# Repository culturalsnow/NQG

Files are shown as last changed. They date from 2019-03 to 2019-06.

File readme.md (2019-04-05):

# NQG: Not Quite Gherkin

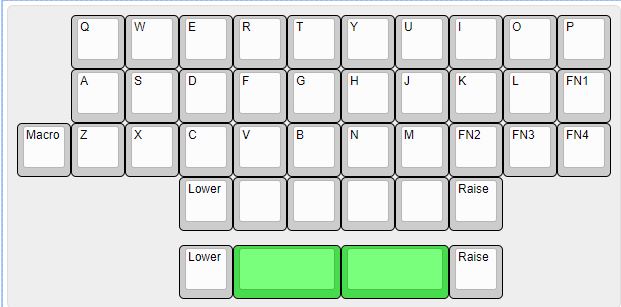
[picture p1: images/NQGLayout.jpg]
NQG


NQG (Not Quite Gherkin) is a 30% ortholinear keyboard with a macro key and dedicated row for thumb keys, made by emptystring studio.

Keyboard Maintainer: [SA_EndlessGame](http://twitter.com/SA_EndlessGame) on twitter  
Hardware Supported: NQG PCB, Pro Micro  
Hardware Availability: Kits are available from [SA_EndlessGame](http://twitter.com/SA_EndlessGame)  

Make example for this keyboard (after setting up your build environment):

    make emptystring/NQG:default

See the [build environment setup](https://docs.qmk.fm/#/getting_started_build_tools) and the [make instructions](https://docs.qmk.fm/#/getting_started_make_guide) for more information. Brand new to QMK? Start with our [Complete Newbs Guide](https://docs.qmk.fm/#/newbs).

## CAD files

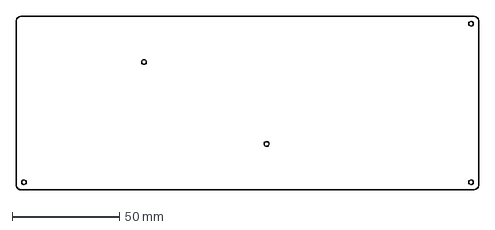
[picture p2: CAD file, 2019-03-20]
PCB/Plates/BottomPlate.dxf
215.4 x 80.8 mm

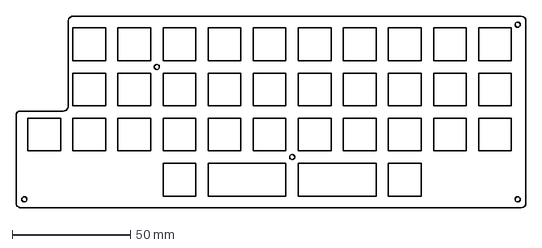
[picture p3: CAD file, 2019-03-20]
PCB/Plates/Top/TopPlate.dxf
215.4 x 80.8 mm

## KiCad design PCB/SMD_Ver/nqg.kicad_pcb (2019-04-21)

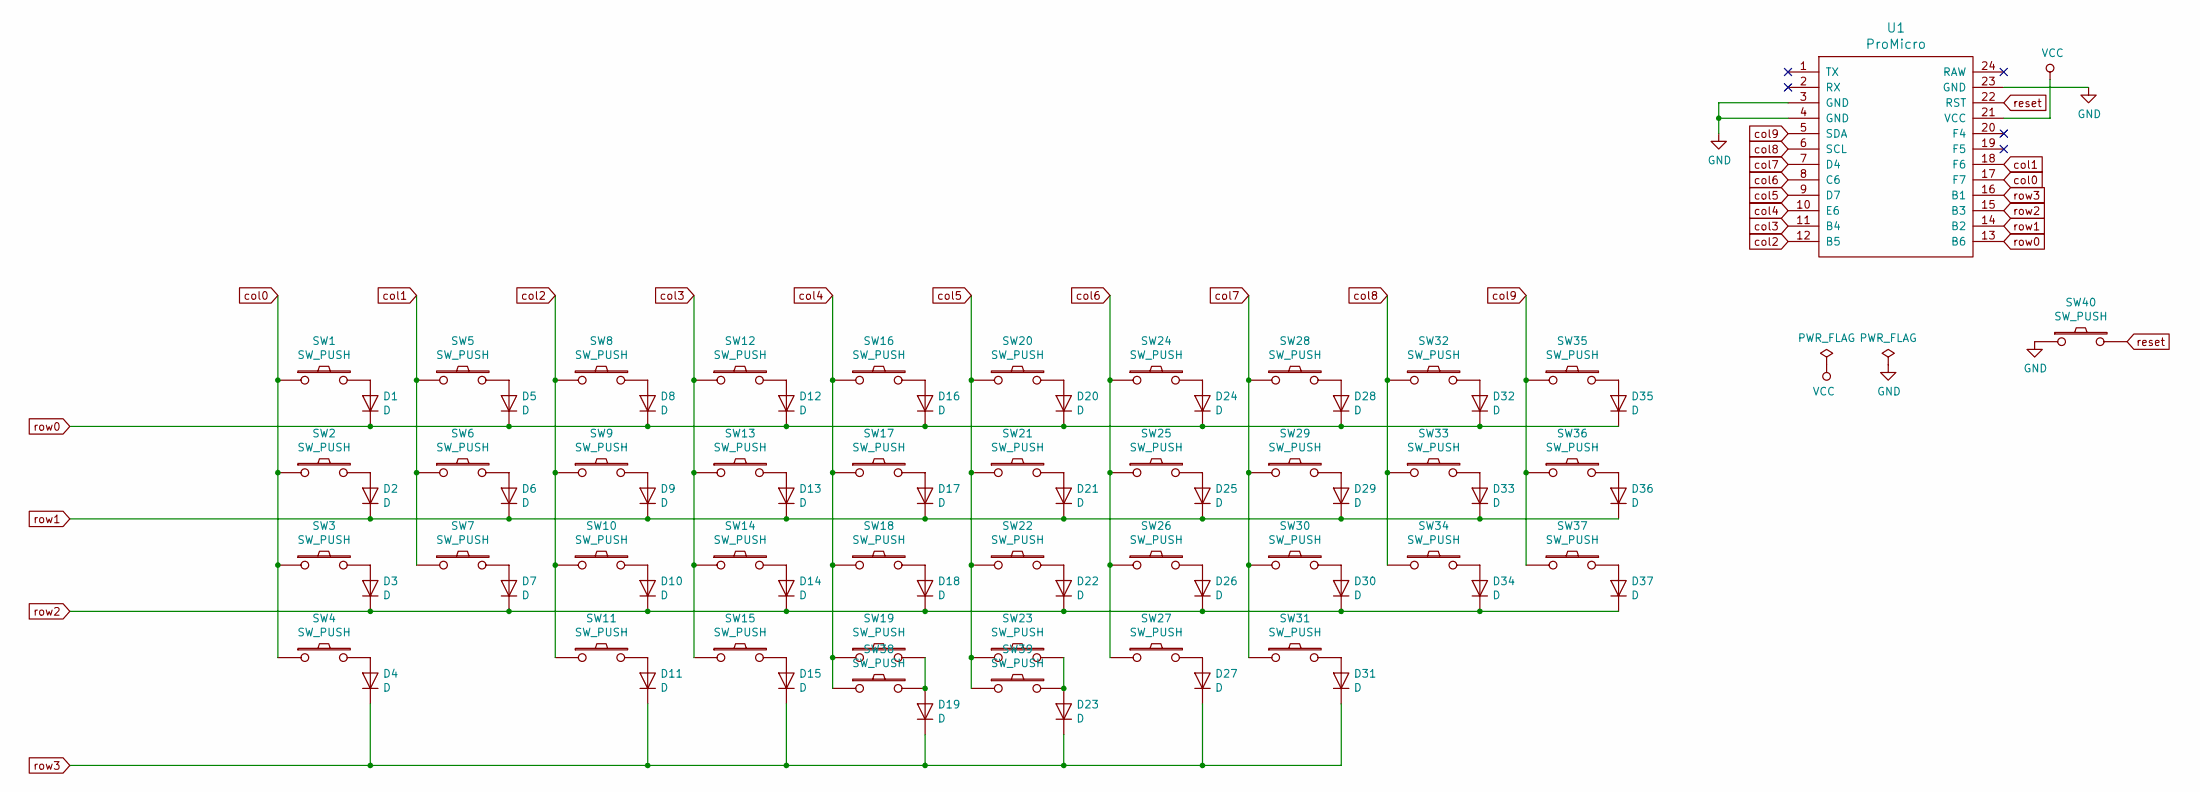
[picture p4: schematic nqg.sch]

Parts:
D1, D2, D3, D4, D5, D6, D7, D8, D9, D10, D11, D12, D13, D14, D15, D16, D17, D18, D19, D20, D21, D22, D23, D24, D25, D26, D27, D28, D29, D30, D31, D32, D33, D34, D35, D36, D37: D; D_SOD-123
SW1, SW2, SW3, SW4, SW5, SW6, SW7, SW8, SW9, SW10, SW11, SW12, SW13, SW14, SW15, SW16, SW17, SW18, SW19, SW20, SW21, SW22, SW23, SW24, SW25, SW26, SW27, SW28, SW29, SW30, SW31, SW32, SW33, SW34, SW35, SW36, SW37, SW38, SW39: SW_PUSH; CherryMX_Hotswap_Back
SW40: SW_PUSH; ResetSW
U1: ProMicro; ProMicro_v2_Backside

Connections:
GND: SW40.1, U1.3 (GND), U1.4 (GND), U1.23 (GND)
unnamed: D1.2 (A), SW1.2
unnamed: D2.2 (A), SW2.2
unnamed: D3.2 (A), SW3.2
unnamed: D4.2 (A), SW4.2
unnamed: D5.2 (A), SW5.2
unnamed: D6.2 (A), SW6.2
unnamed: D7.2 (A), SW7.2
unnamed: D8.2 (A), SW8.2
unnamed: D9.2 (A), SW9.2
unnamed: D10.2 (A), SW10.2
unnamed: D11.2 (A), SW11.2
unnamed: D12.2 (A), SW12.2
unnamed: D13.2 (A), SW13.2
unnamed: D14.2 (A), SW14.2
unnamed: D15.2 (A), SW15.2
unnamed: D16.2 (A), SW16.2
unnamed: D17.2 (A), SW17.2
unnamed: D18.2 (A), SW18.2
unnamed: D19.2 (A), SW19.2, SW38.2
unnamed: D20.2 (A), SW20.2
unnamed: D21.2 (A), SW21.2
unnamed: D22.2 (A), SW22.2
unnamed: D23.2 (A), SW23.2, SW39.2
unnamed: D24.2 (A), SW24.2
unnamed: D25.2 (A), SW25.2
unnamed: D26.2 (A), SW26.2
unnamed: D27.2 (A), SW27.2
unnamed: D28.2 (A), SW28.2
unnamed: D29.2 (A), SW29.2
unnamed: D30.2 (A), SW30.2
unnamed: D31.2 (A), SW31.2
unnamed: D32.2 (A), SW32.2
unnamed: D33.2 (A), SW33.2
unnamed: D34.2 (A), SW34.2
unnamed: D35.2 (A), SW35.2
unnamed: D36.2 (A), SW36.2
unnamed: D37.2 (A), SW37.2
VCC: U1.21 (VCC)
col0: SW1.1, SW2.1, SW3.1, SW4.1, U1.17 (F7)
col1: SW5.1, SW6.1, SW7.1, U1.18 (F6)
col2: SW8.1, SW9.1, SW10.1, SW11.1, U1.12 (B5)
col3: SW12.1, SW13.1, SW14.1, SW15.1, U1.11 (B4)
col4: SW16.1, SW17.1, SW18.1, SW19.1, SW38.1, U1.10 (E6)
col5: SW20.1, SW21.1, SW22.1, SW23.1, SW39.1, U1.9 (D7)
col6: SW24.1, SW25.1, SW26.1, SW27.1, U1.8 (C6)
col7: SW28.1, SW29.1, SW30.1, SW31.1, U1.7 (D4)
col8: SW32.1, SW33.1, SW34.1, U1.6 (SCL)
col9: SW35.1, SW36.1, SW37.1, U1.5 (SDA)
reset: SW40.2, U1.22 (RST)
row0: D1.1 (K), D5.1 (K), D8.1 (K), D12.1 (K), D16.1 (K), D20.1 (K), D24.1 (K), D28.1 (K), D32.1 (K), D35.1 (K), U1.13 (B6)
row1: D2.1 (K), D6.1 (K), D9.1 (K), D13.1 (K), D17.1 (K), D21.1 (K), D25.1 (K), D29.1 (K), D33.1 (K), D36.1 (K), U1.14 (B2)
row2: D3.1 (K), D7.1 (K), D10.1 (K), D14.1 (K), D18.1 (K), D22.1 (K), D26.1 (K), D30.1 (K), D34.1 (K), D37.1 (K), U1.15 (B3)
row3: D4.1 (K), D11.1 (K), D15.1 (K), D19.1 (K), D23.1 (K), D27.1 (K), D31.1 (K), U1.16 (B1)

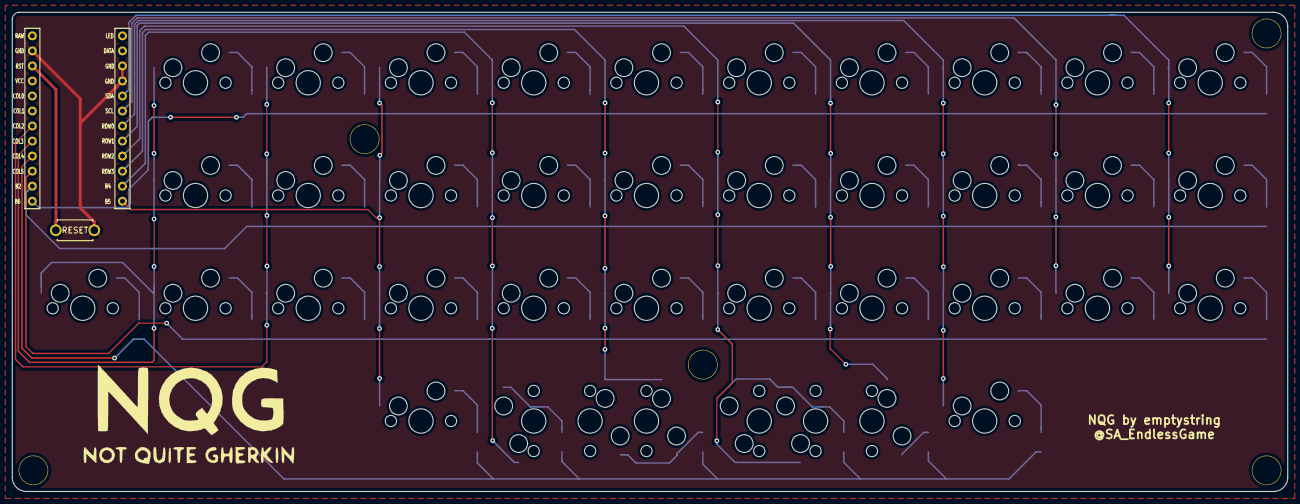
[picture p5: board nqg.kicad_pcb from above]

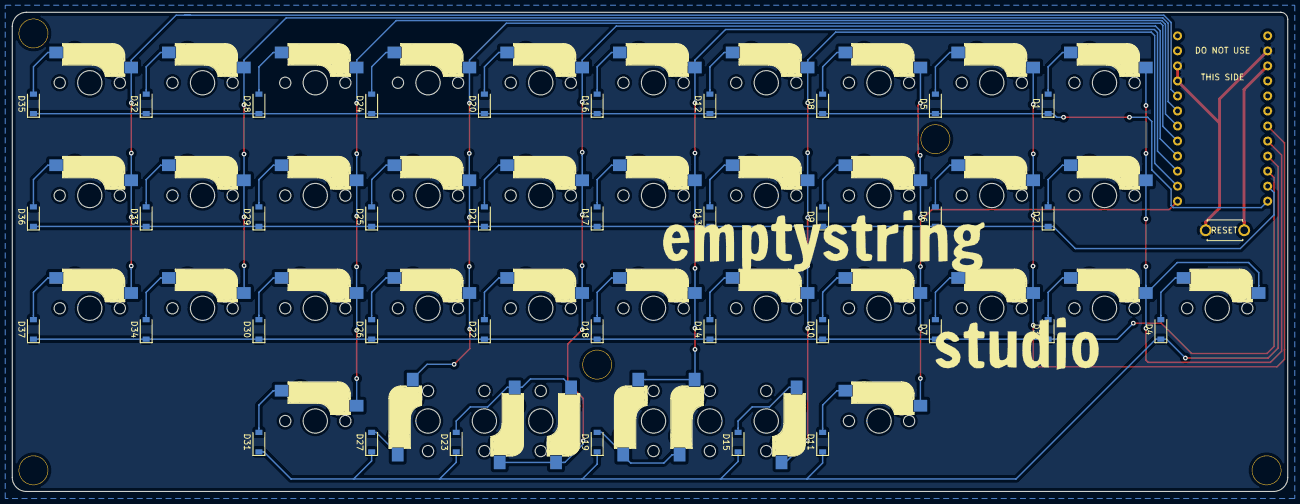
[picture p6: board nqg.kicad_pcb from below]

Board: 2 copper layers, 215.5 x 81.0 mm, 83 parts (37 on the bottom side), 53 nets.

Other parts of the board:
Ref**: Val**; HOLE
Ref**#2, Ref**#3, Ref**#4, Ref**#5: Val**; HOLE

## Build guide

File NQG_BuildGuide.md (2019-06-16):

# NQG Build Guide

NQG

NQG (Not Quite Gherkin) is a 30% ortholinear keyboard with a macro key and dedicated row for thumb keys, made by emptystring studio.

What the kit includes:  
PCB x1  
Top Plate x1  
Bottom Plate x1

Diodes x40 (37 + 3 spares)  
Kailh Hotswap Socket x40 (37 + 3 spares)  
Reset Button x1

M2 Screws x12  
M2 Spacers x6  
Rubber Feet x8 (4 short + 4 tall)

You need to supply your own:  
Pro Micro & Pins x1 set  
Switches x35-37, depending on layout  
1U and 2U keycaps, depending on layout

The front of the PCB looks like this. The name of the keyboard is on this side.
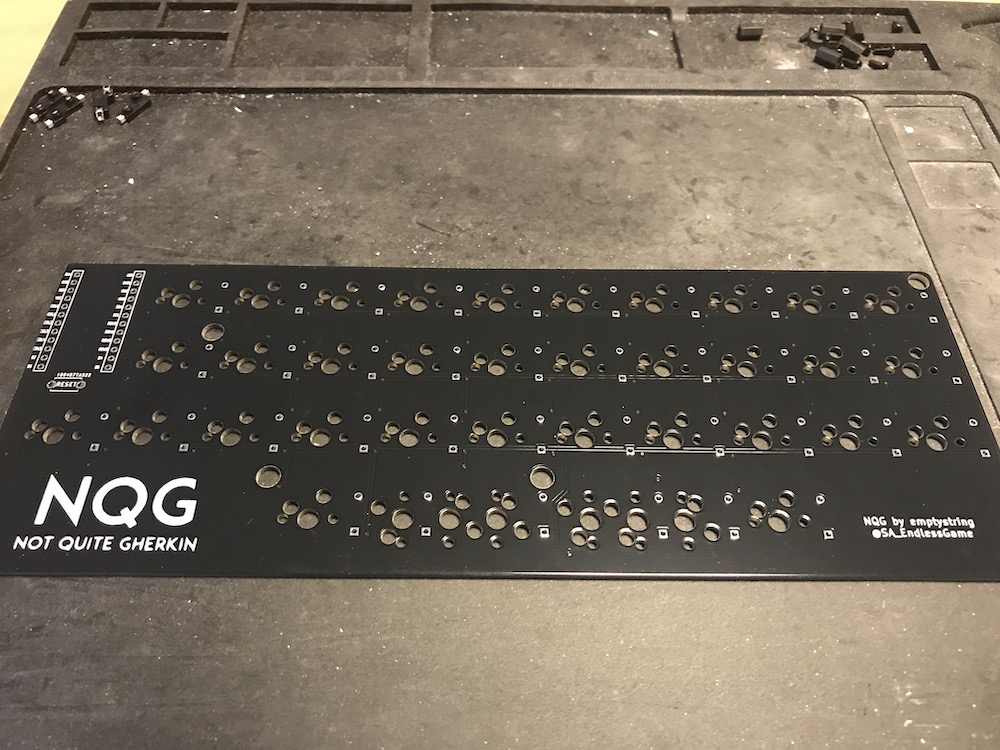
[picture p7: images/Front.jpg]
Front


The back of the PCB looks like this. The name of the studio is on this side.
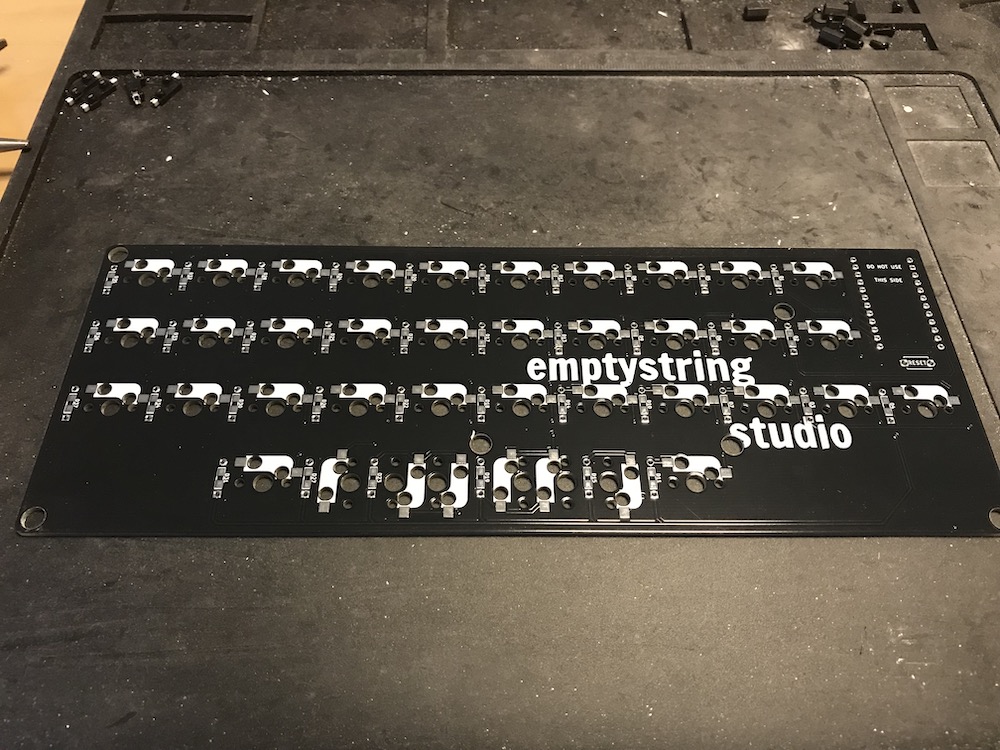
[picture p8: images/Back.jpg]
Back


Diodes are mounted on the back of the PCB. The black line faces towards the square hole/bottom row.  
If you are using SMD diodes (SOD123), then the line on the diode will face towards the square hole/bottom row.

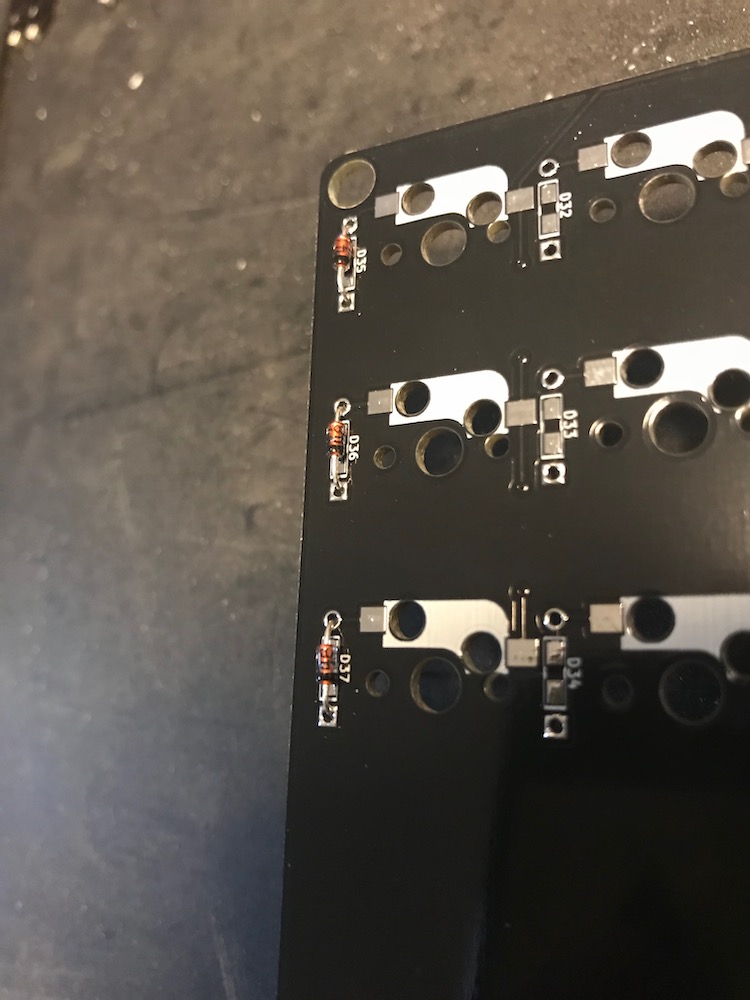
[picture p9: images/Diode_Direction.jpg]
Diode


Bend their legs, insert them through the holes on the board and twist them to make sure they stay in place.

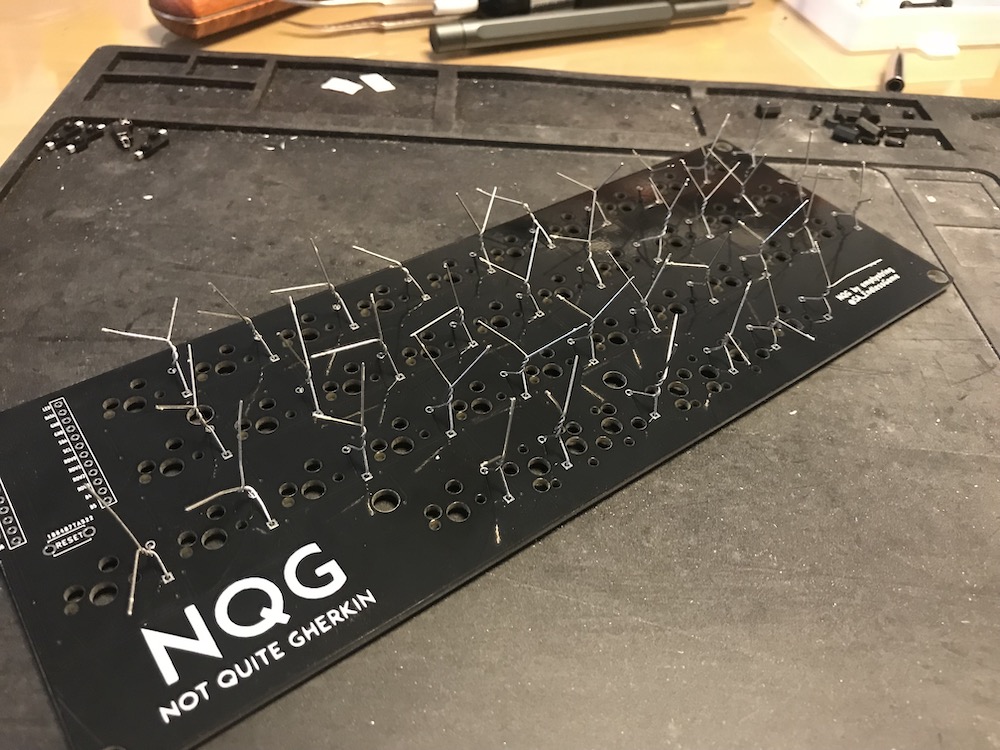
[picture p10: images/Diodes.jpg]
Diode


After soldering the diodes and cutting their legs off, apply solder to the pads for hotswap sockets.

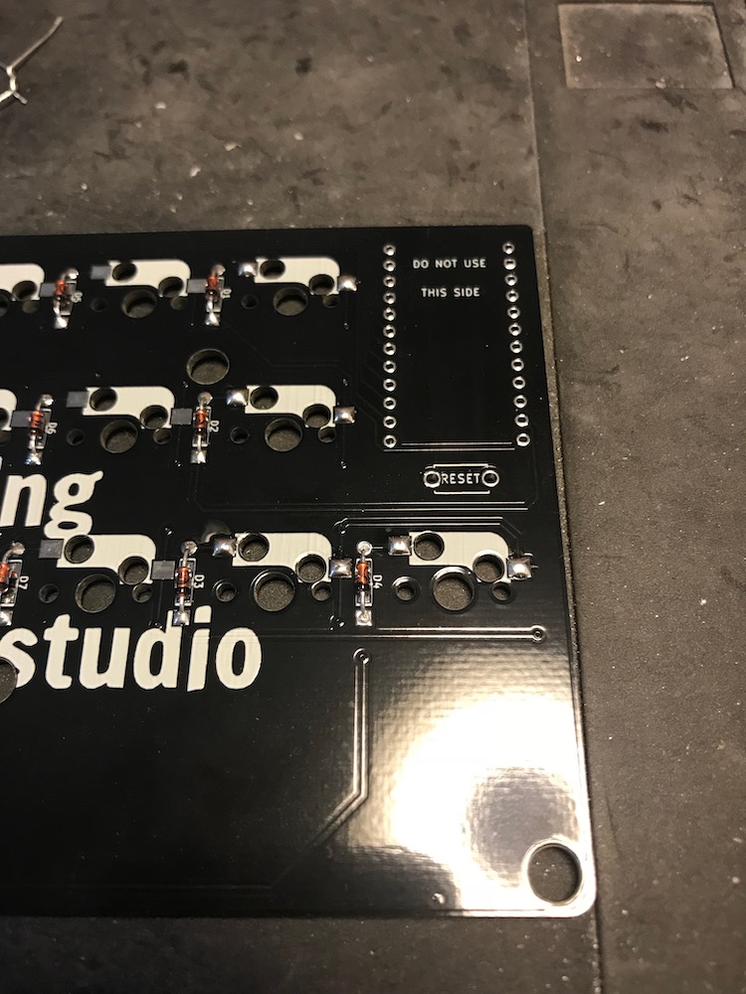
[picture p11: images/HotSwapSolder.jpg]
Hotswap


Then solder the sockets on by heating the solder and pushing the socket down either with your finger or a tweezer.

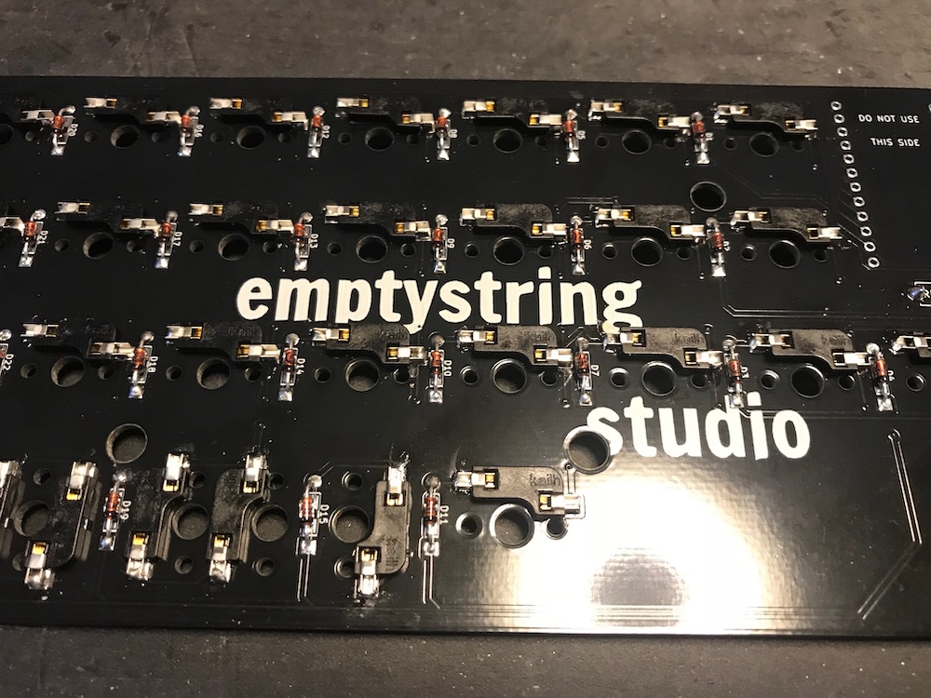
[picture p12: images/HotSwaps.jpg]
Hotswap


The reset button goes on the front of the PCB.

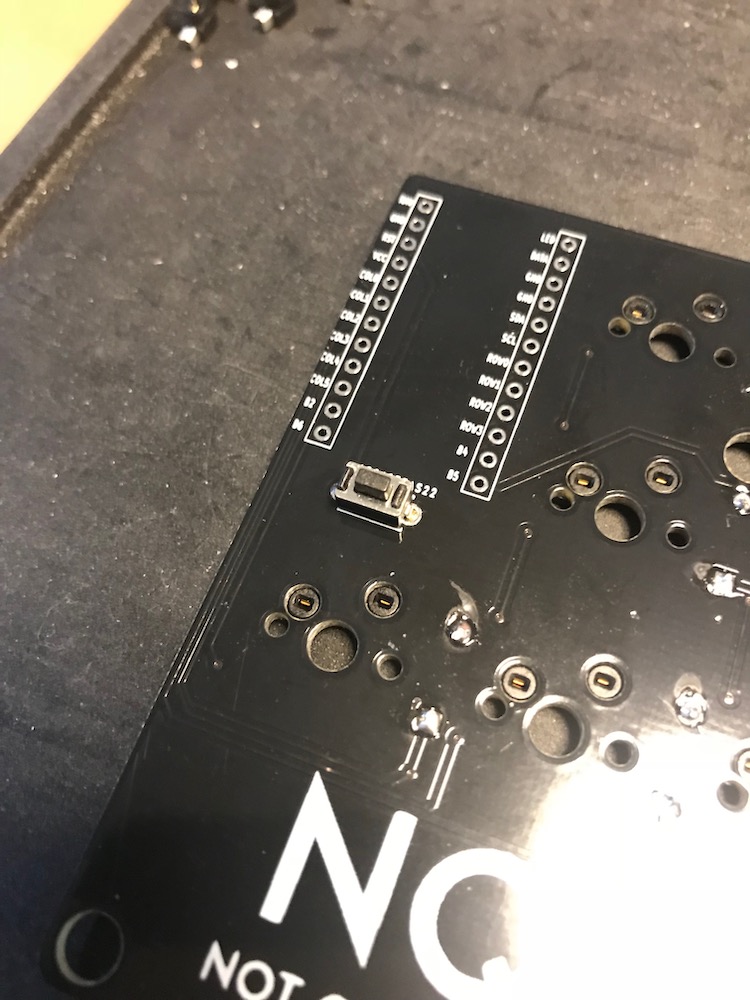
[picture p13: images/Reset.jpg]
Reset


The Pro Micro also goes on the front of the PCB.  
Insert the pins, use some tape to hold them down and solder them from the back.  
Then set the Pro Micro on the pins. THE SIDE WITH THE CHIPS FACES DOWN.

This PCB is compatible with the Japanese-made spring header in mind, which makes the Pro Micro removable.  
Please see the [Helix Build Guide](https://github.com/MakotoKurauchi/helix/blob/master/Doc/buildguide_en.md) on how to solder those headers.

Add switches to the plate and push them into the sockets.  
Switches for the bottom row have a different orientation than the rest.  
Pay attention to the direction of the sockets!  
The bottom row can be configured as follows:  
1U / 2U / 2U / 1U  
1U / 1U / 1U / 2U / 1U  
1U / 2U / 1U / 1U / 1U  
1U / 1U / 1U / 1U / 1U / 1U

Install spacers on the back plate, then place the switch plate + PCB on top of it, and tighten the screws.

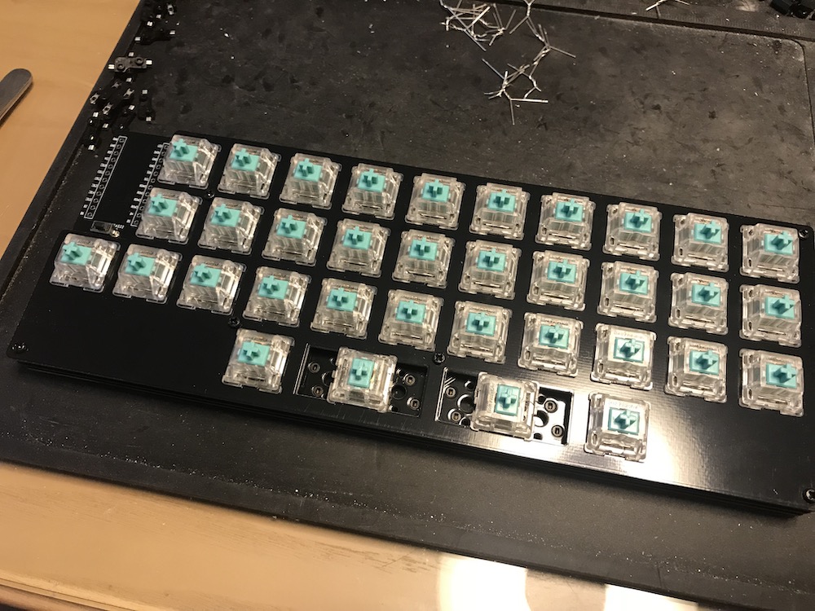
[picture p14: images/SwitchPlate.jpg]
Switches


Install rubber feet based on your preference.

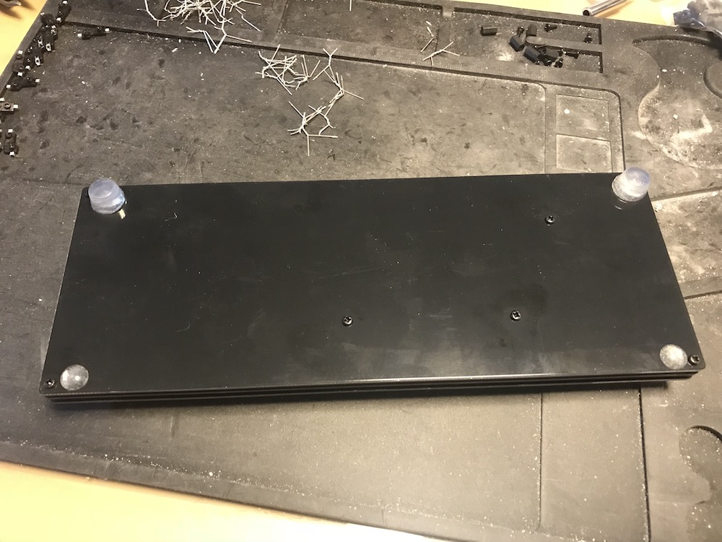
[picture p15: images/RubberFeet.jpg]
Feet


Then put on your favorite keycaps and you're done!

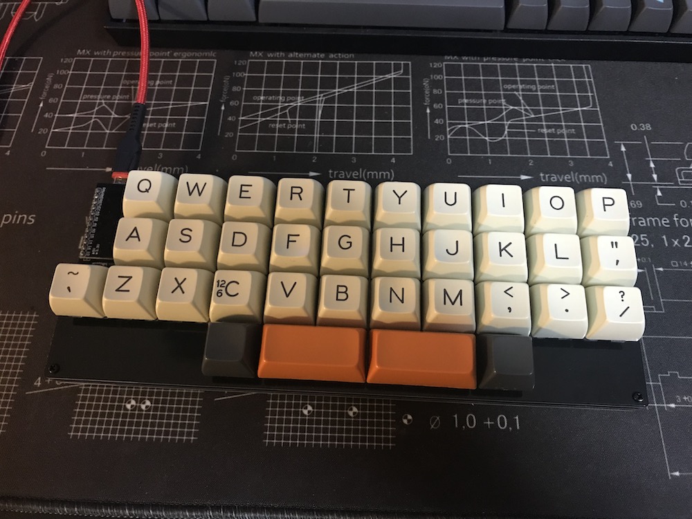
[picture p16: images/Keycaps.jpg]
Keycaps


Make example for this keyboard (after setting up your build environment):

    make emptystring/NQG:default

See the [build environment setup](https://docs.qmk.fm/#/getting_started_build_tools) and the [make instructions](https://docs.qmk.fm/#/getting_started_make_guide) for more information.

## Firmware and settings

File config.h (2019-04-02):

/*
Copyright 2019 Bernard Shih (twitter: @SA_EndlessGame)

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
You should have received a copy of the GNU General Public License
along with this program.  If not, see <http://www.gnu.org/licenses/>.
*/

#pragma once

#include "config_common.h"

/* USB Device descriptor parameter */
#define VENDOR_ID       0x0076
#define PRODUCT_ID      0x0037
#define DEVICE_VER      0x0100
#define MANUFACTURER    emptystring
#define PRODUCT         NQG
#define DESCRIPTION     30% ortholinear keyboard

/* key matrix size */
#define MATRIX_ROWS 4
#define MATRIX_COLS 10

/* key matrix pins */
#define MATRIX_ROW_PINS {B6, B2, B3, B1}
#define MATRIX_COL_PINS {F7, F6, B5, B4, E6, D7, C6, D4, D0, D1}


/* COL2ROW or ROW2COL */
#define DIODE_DIRECTION COL2ROW

#define TAPPING_TERM 200

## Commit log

2019-03-16 first push 20190317
    [nqg.kicad_pcb, nqg.sch]
2019-03-16 added mounting holes
    [nqg.kicad_pcb]
2019-03-17 rounded edges
    [nqg-Dwgs.User.dxf, nqg-Edge.Cuts.dxf, nqg-F.CrtYd.dxf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]
2019-03-18 added gerber zip
    [nqg-B.Cu.gbr, nqg-B.Mask.gbr, nqg-B.SilkS.gbr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]
2019-03-19 new dxf for plate added
    [nqg-Dwgs.User.dxf, nqg-Edge.Cuts.dxf, nqg-F.CrtYd.dxf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]
2019-03-20 rerouted, larger holes, plates
    [BottomPlate.dxf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]
2019-03-25 redid wiring, firmware halfway done
    [nqg-Dwgs.User.dxf, nqg-Edge.Cuts.dxf, nqg-F.CrtYd.dxf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]
2019-03-30 beta pcb added
    [nqg_beta_01.kicad_pcb, nqg_beta_01.sch]
2019-04-21 added THD version, removed beta_01
    [nqgTHD.kicad_pcb, nqgTHD.sch, nqg_beta_01.kicad_pcb]
2019-04-21 now switch # matches up with diode # in SMD version as well
    [nqg.kicad_pcb, nqg.sch]
2019-06-08 added new screw to THD version, created new plates with new screw locations
    [BottomPlate-B_Cu.gbr, BottomPlate-B_Mask.gbr, BottomPlate-B_SilkS.gbr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]

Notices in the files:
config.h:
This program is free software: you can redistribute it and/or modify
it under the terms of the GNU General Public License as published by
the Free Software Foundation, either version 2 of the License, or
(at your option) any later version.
